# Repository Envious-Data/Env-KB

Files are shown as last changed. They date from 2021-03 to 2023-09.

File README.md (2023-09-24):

# Env-KB
 A custom mechanical keyboard inspired by the CFTKB Mysterium.
 
- Project Name: EnvKB80
- Nickname: Delirium

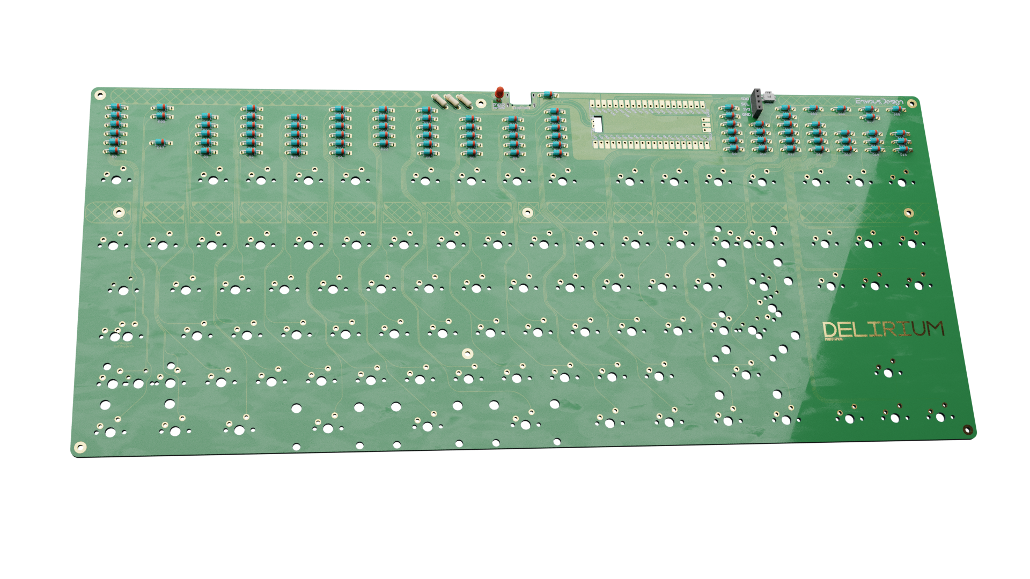
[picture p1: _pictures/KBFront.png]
Updated PCB


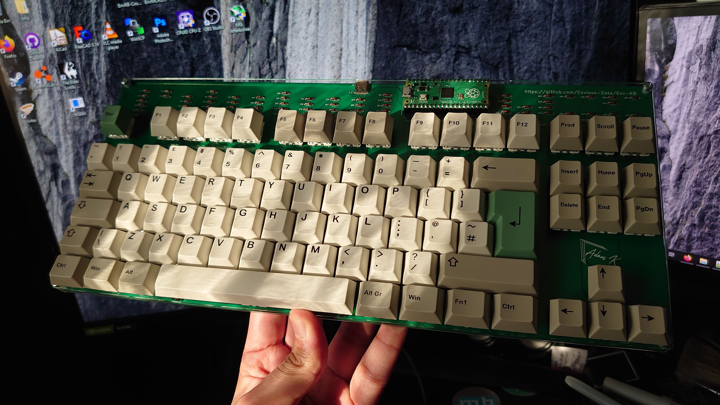
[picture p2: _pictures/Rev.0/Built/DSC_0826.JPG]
Rev0 Build


### About:
This is a raspberry pi pico powered keyboard I designed as I wanted something similar to a CFTKB Mysterium but easier to solder and a bit more robustly designed.

### Firmware
Pre-compiled firmwares can be found [here](https://github.com/Envious-Data/EnvKB-QMK/tree/main/_PREBUILTFIRMWARES)
- to flash a raspberry pi pico or any RP2040 board you need to hold the bootsel button while plugging in the USB, it'll show up as a USB drive called RP2-boot, you can then drag and drop a UF2 firmware file onto the pico, it will reboot its self.

### Parts
- 1x Type-C-31-M-14
- 90x 1n4148 DO-35
- 90x MX keyboard switches (5 pin advised if without switch plate)
- 3x 5.1K 1/4W resistors
- 1x 3mm LED
- 1x 1x04 2.54mm pin socket (optional oled)
- 1x Panasonic EVQPU SMD switch (optional reset)
- raspberry pi pico

- 10x m2 female standoffs 10mm 
- 20x m2 screws <5mm

(this list may not be totally accurate since I often forget what has changed inbetween when the readme is updated.

### Building
Most part orientations should be marked on the PCB however it is important to note that you NEED to connect the pads under the MCU to the respective pads on the board for USB to work, you also need 5.1K resistors to work with USB PD compatible ports.

the type-c port may be difficult for some to solder so use loads of flux and minimal amounts of solder, its best to solder the large 4 outer pins of the shell first.

### Why a RPI Pico?
uh well why not, I think it would be a nice example for people to use as a example.
When I came up with the idea of this keyboard there was 1 other raspberry pi pico keyboard so I decided it would be cool to make a keyboard.

### PCBWAY

PCBWAY (http://pcbway.com)

[PCBWAY](http://pcbway.com) Kindly sponsored a batch of PCBs of which you can see [pictures](_pictures/Hotswap/) of inside the pictures folder.

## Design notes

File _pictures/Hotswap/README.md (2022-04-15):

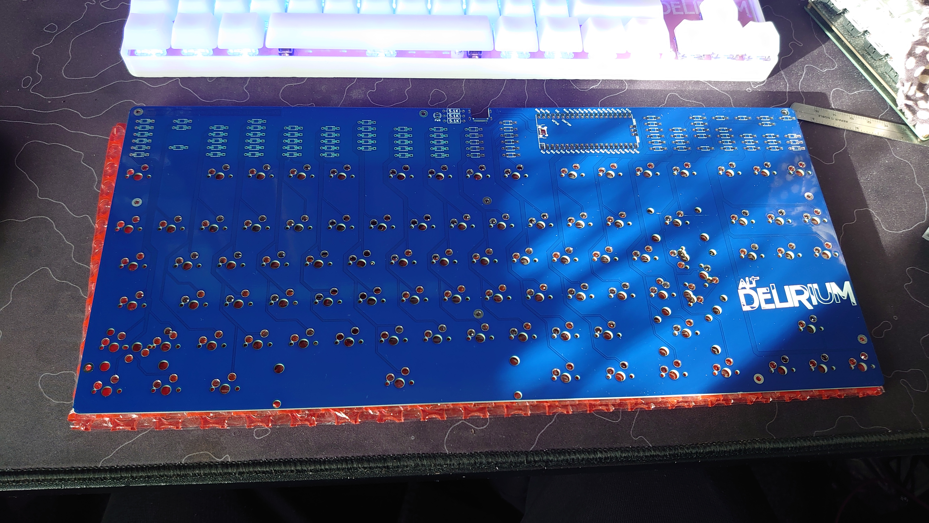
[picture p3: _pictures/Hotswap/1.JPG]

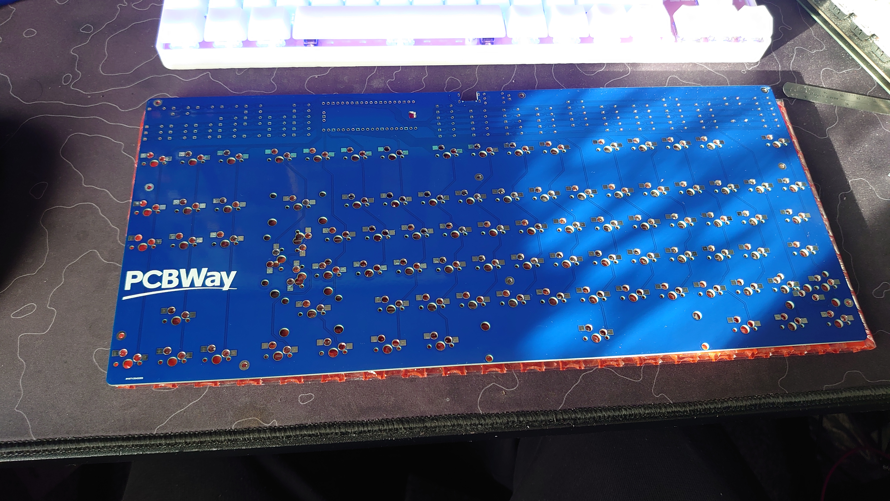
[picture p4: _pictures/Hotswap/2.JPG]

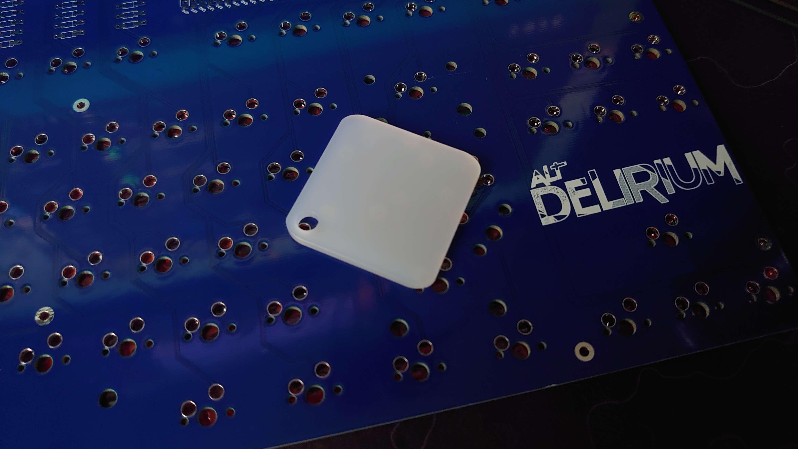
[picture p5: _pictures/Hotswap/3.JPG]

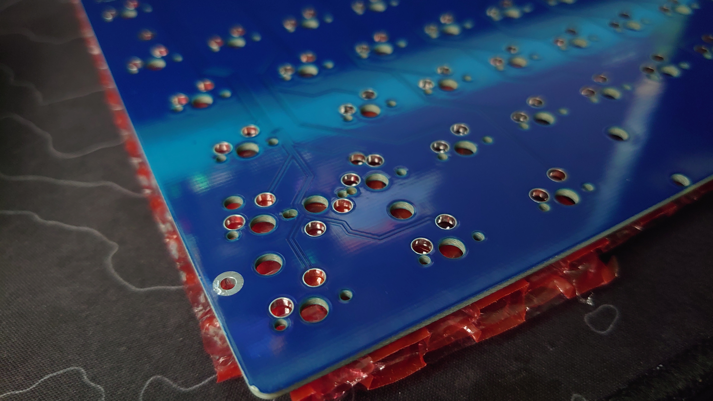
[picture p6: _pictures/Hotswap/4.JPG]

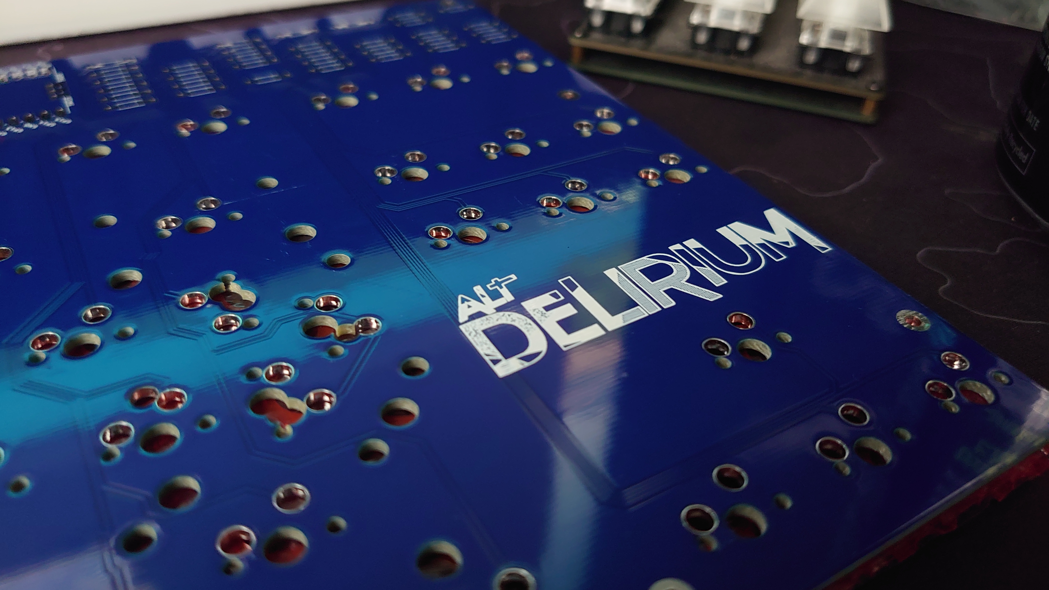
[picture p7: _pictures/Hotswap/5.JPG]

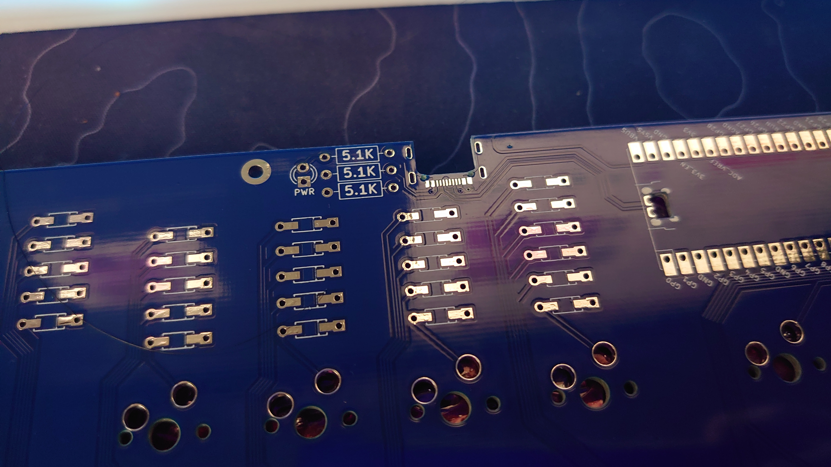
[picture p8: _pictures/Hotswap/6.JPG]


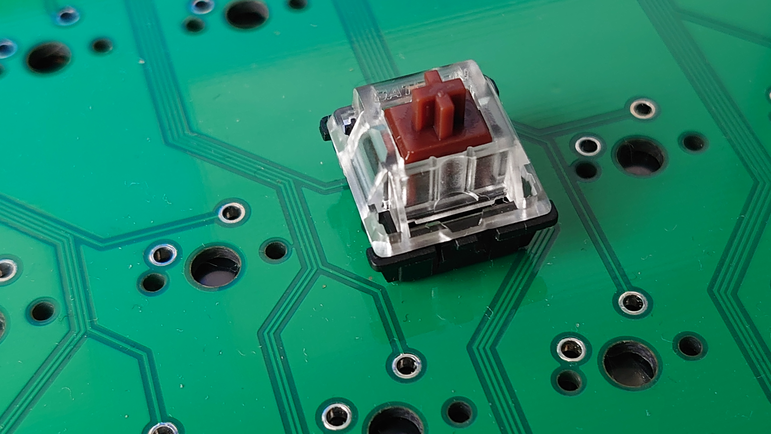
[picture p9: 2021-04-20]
_pictures/Rev.0/PCB10.JPG

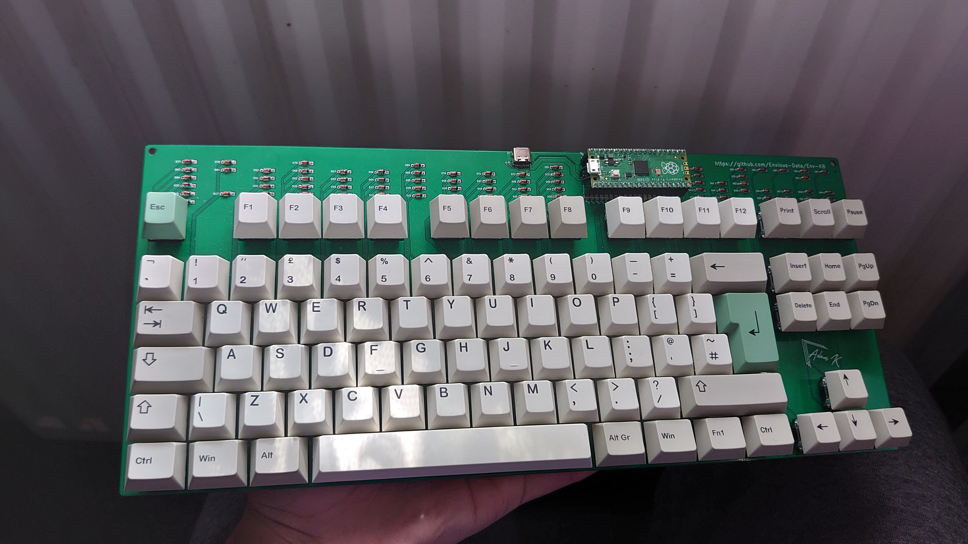
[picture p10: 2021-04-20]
_pictures/Rev.0/PCB3.JPG

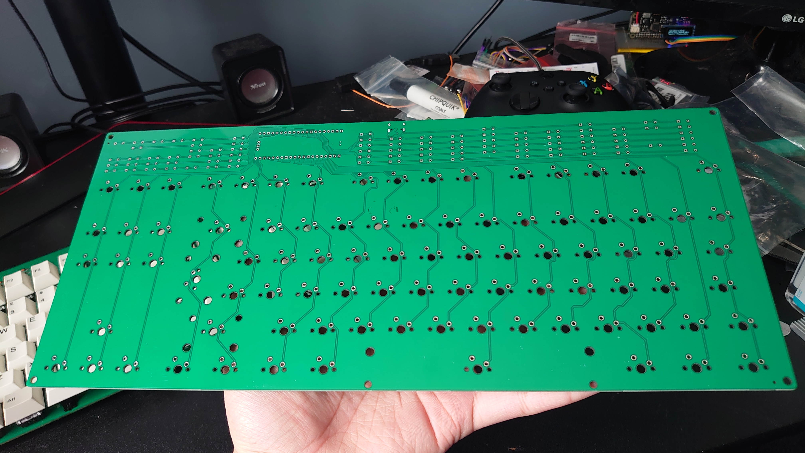
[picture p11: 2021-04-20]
_pictures/Rev.0/PCB8.JPG

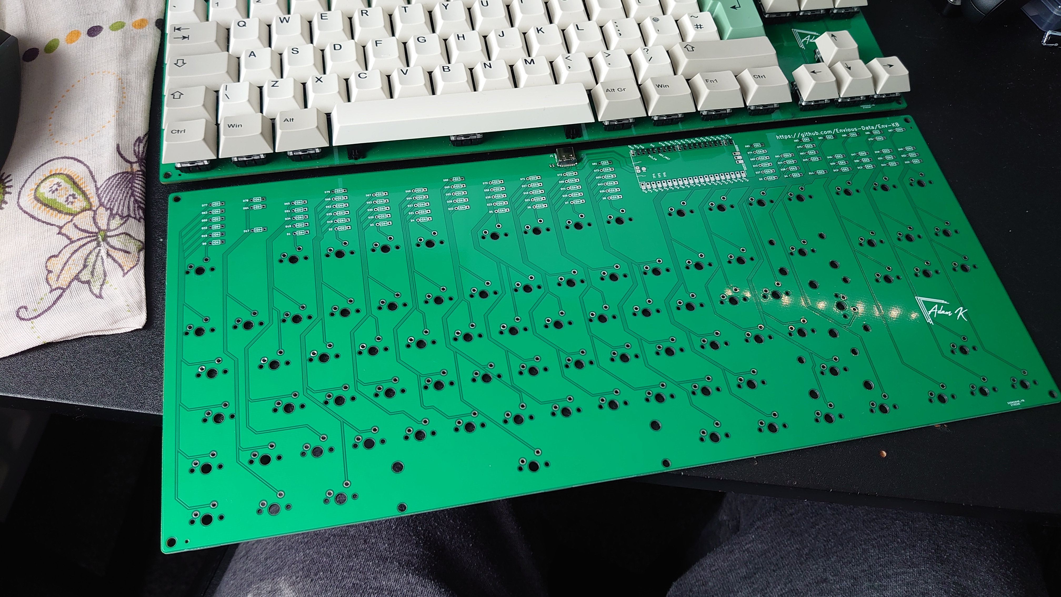
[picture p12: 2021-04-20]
_pictures/Rev.0/PCB6.JPG

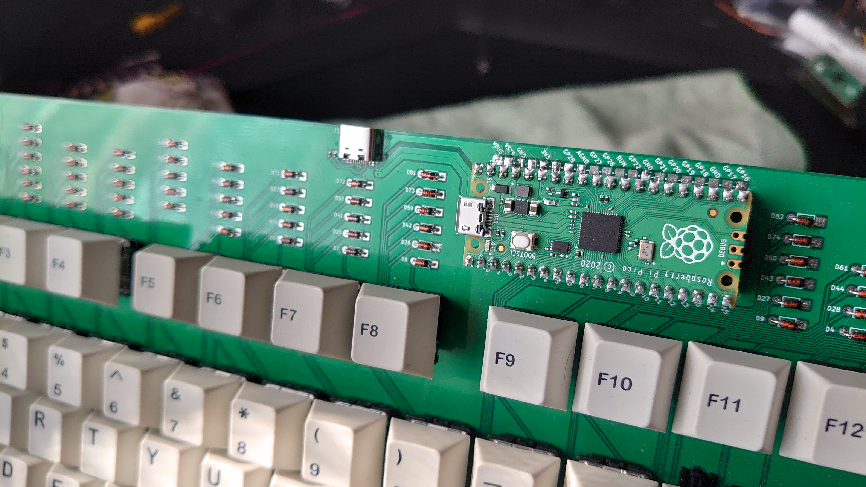
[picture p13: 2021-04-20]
_pictures/Rev.0/PCB5.JPG

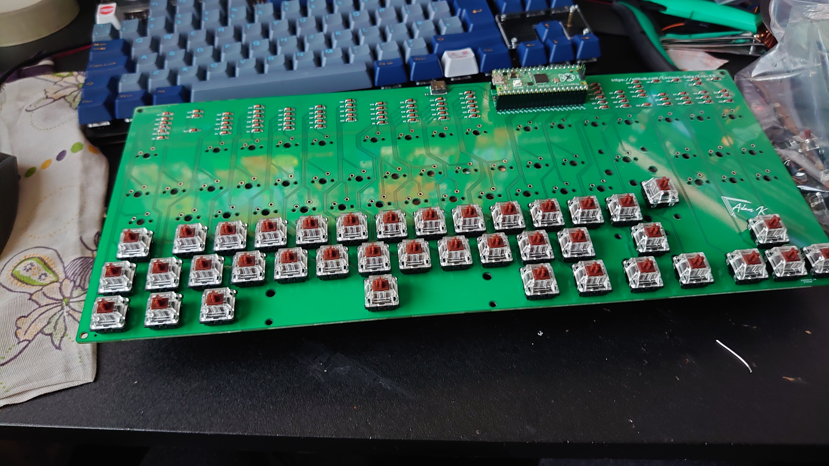
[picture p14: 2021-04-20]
_pictures/Rev.0/PCB1.JPG

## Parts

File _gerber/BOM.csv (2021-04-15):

Comment | Designator | Footprint | LCSC
D | D0,D1,D2,D3,D4,D5,D6,D7,D8,D9,D10,D11,D12,D13,D14,D15,D16,D17,D18,D19,D20,D21,D22,D23,D24,D25,D26,D27,D28,D29,D30,D31,D32,D33,D34,D35,D36,D37,D38,D39,D40,D41,D42,D43,D44,D45,D46,D47,D48,D49,D50,D51,D52,D53,D54,D55,D56,D57,D58,D59,D60,D61,D62,D63,D64,D65,D66,D67,D68,D69,D70,D71,D72,D73,D74,D75,D76,D77,D78,D79,D80,D81,D82,D83,D84,D85,D86,D87,D88 | CFTKB Bits:D_DO-35_SOD27_P5.08mm_Horizontal
MountingHole | H0,H1,H2,H3,H4,H5,H6,H7,H8,H9,H10 | MountingHole:MountingHole_2.2mm_M2
Conn_01x04 | I2CHeader0 | Connector_PinSocket_2.54mm:PinSocket_1x04_P2.54mm_Vertical
TYPE-C-31-M-12 | J0 | EM_Extras:USB_C_Receptacle_HRO_TYPE-C-31-M-12
KEYSW | K_0,K_1,K_2,K_3,K_4,K_5,K_6,K_7,K_8,K_9,K_10,K_11,K_12,K_13,K_14,K_15,K_16,K_17,K_18,K_19,K_20,K_21,K_22,K_23,K_24,K_25,K_26,K_27,K_28,K_30,K_31,K_32,K_34,K_35,K_36,K_37,K_38,K_39,K_40,K_41,K_42,K_43,K_44,K_45,K_47,K_48,K_49,K_51,K_52,K_53,K_54,K_55,K_56,K_57,K_58,K_59,K_60,K_61,K_62,K_65,K_66,K_67,K_68,K_69,K_70,K_71,K_72,K_73,K_74,K_75,K_77,K_86,K_87,K_88 | MX_only:MXOnly-1U-NoLED
KEYSW | K_29 | MX_only:MXOnly-2U-NoLED
KEYSW | K_33,K_46 | MX_only:MXOnly-1.5U-NoLED
KEYSW | K_50 | MX_only:MXOnly-1.75U-NoLED
MX-NoLED | K_63 | MX_only:MXOnly-ISO-ROTATED-ReversedStabilizers-NoLED
MX-NoLED | K_63B1 | MX_only:MXOnly-2.25U-NoLED
KEYSW | K_64,K_78,K_79,K_80,K_82,K_83,K_84,K_85 | MX_only:MXOnly-1.25U-NoLED
KEYSW | K_64B1 | MX_only:MXOnly-2.25U-NoLED
KEYSW | K_76 | MX_only:MXOnly-2.75U-NoLED
KEYSW | K_81 | MX_only:MXOnly-6.25U-ReversedStabilizers-NoLED
Green Power Led | PowerLED0 | LED_SMD:LED_0805_2012Metric_Castellated
1K Resistor | PowerLedResistor0 | Resistor_SMD:R_0805_2012Metric
5.1kohm | RESISTOR0,RESISTOR1 | Resistor_SMD:R_0402_1005Metric
Pico | RPI0 | EM_Extras:RPi_Pico_SMD_TH
B3F-1000 | SW-RST0 | EM_Extras:SW_B3F-1000

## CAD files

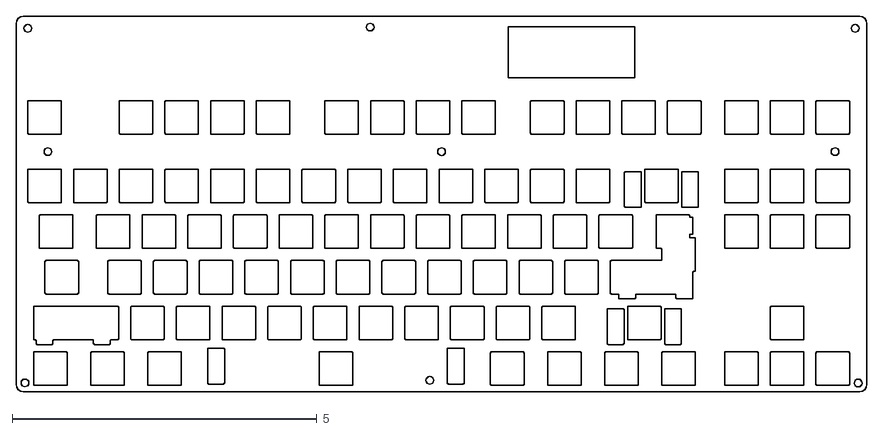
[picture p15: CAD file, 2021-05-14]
_gerber/EnvKB-R1-Front.dxf
14.0 x 6.16

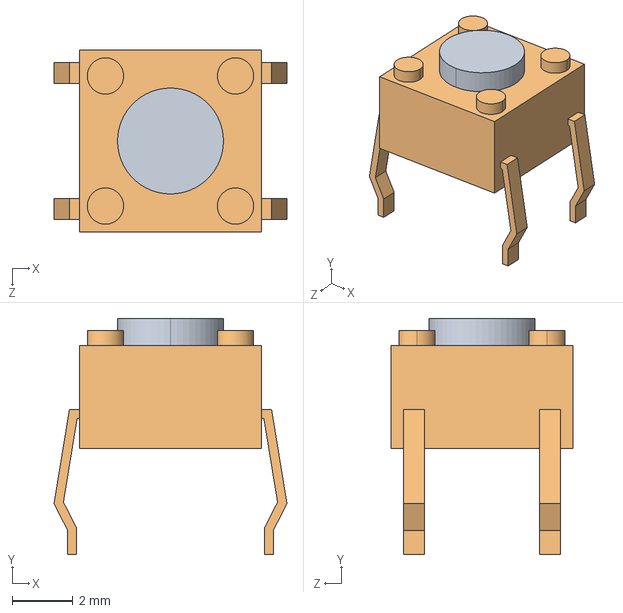
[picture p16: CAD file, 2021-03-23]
_KiCadLibs/Schematic_Library/B3F-1000.step
7.70 x 7.80 x 6.00 mm
B3F_1000_BUTTON
B3F_1000_BASE

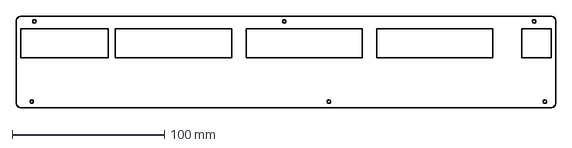
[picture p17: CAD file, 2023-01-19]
Production Files/Laser Cut files/TopCover.dxf
353.7 x 59.7 mm

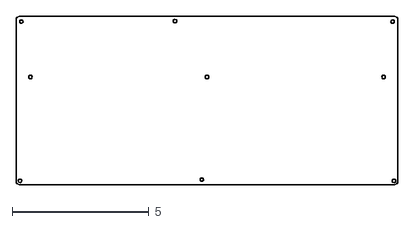
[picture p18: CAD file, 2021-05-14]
_gerber/EnvKB-R1-Back.dxf
14.0 x 6.16

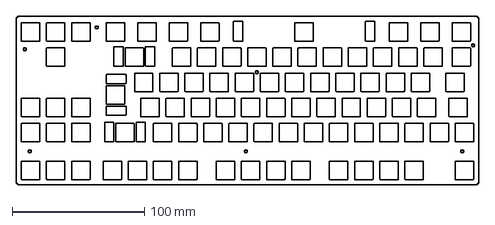
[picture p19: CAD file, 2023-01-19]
Production Files/Laser Cut files/SwitchPlate.dxf
350.6 x 127.8 mm

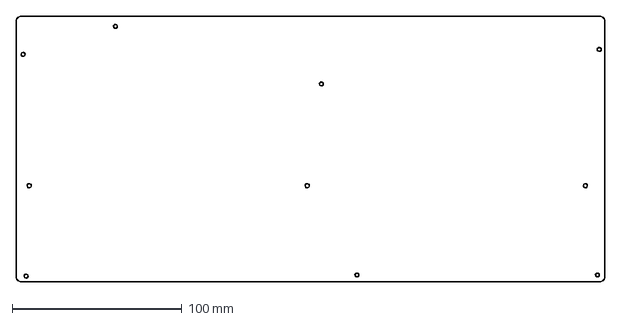
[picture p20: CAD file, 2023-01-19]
Production Files/Laser Cut files/BackPlate.dxf
347.0 x 156.3 mm

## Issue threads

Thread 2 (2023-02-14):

Help with HS + RGB version

racsor17, 2023-02-14:
Hi, this is my first time building my own keyboard. Do I need to get and solder different materials that aren't in the list? Like RGB LEDs or anything to do the "hot-swap thing"? There is any building guide? To order the PCB in PCBWAY, I just have to drag the files and buy it?
I just love this keyboard, you've done such a great job!

racsor17, 2023-02-14:
LED's needsSMT solder??

Envious-Data, 2023-02-14:
You'll have to download KiCad and generate gerbers, CPL and BOM for PCB way since what you might find in the gerber folder is for JLCPCB.

the LEDs can be hand soldered but they can be difficult if you get them from aliexpress, you are looking for SK6812 mini-e.

the hotswap sockets are typical kailh ones you can buy those from a number of stores.

diodes are 1n4148 Do-35s

racsor17, 2023-02-16:
Thank you!

Closed 2023-02-16.

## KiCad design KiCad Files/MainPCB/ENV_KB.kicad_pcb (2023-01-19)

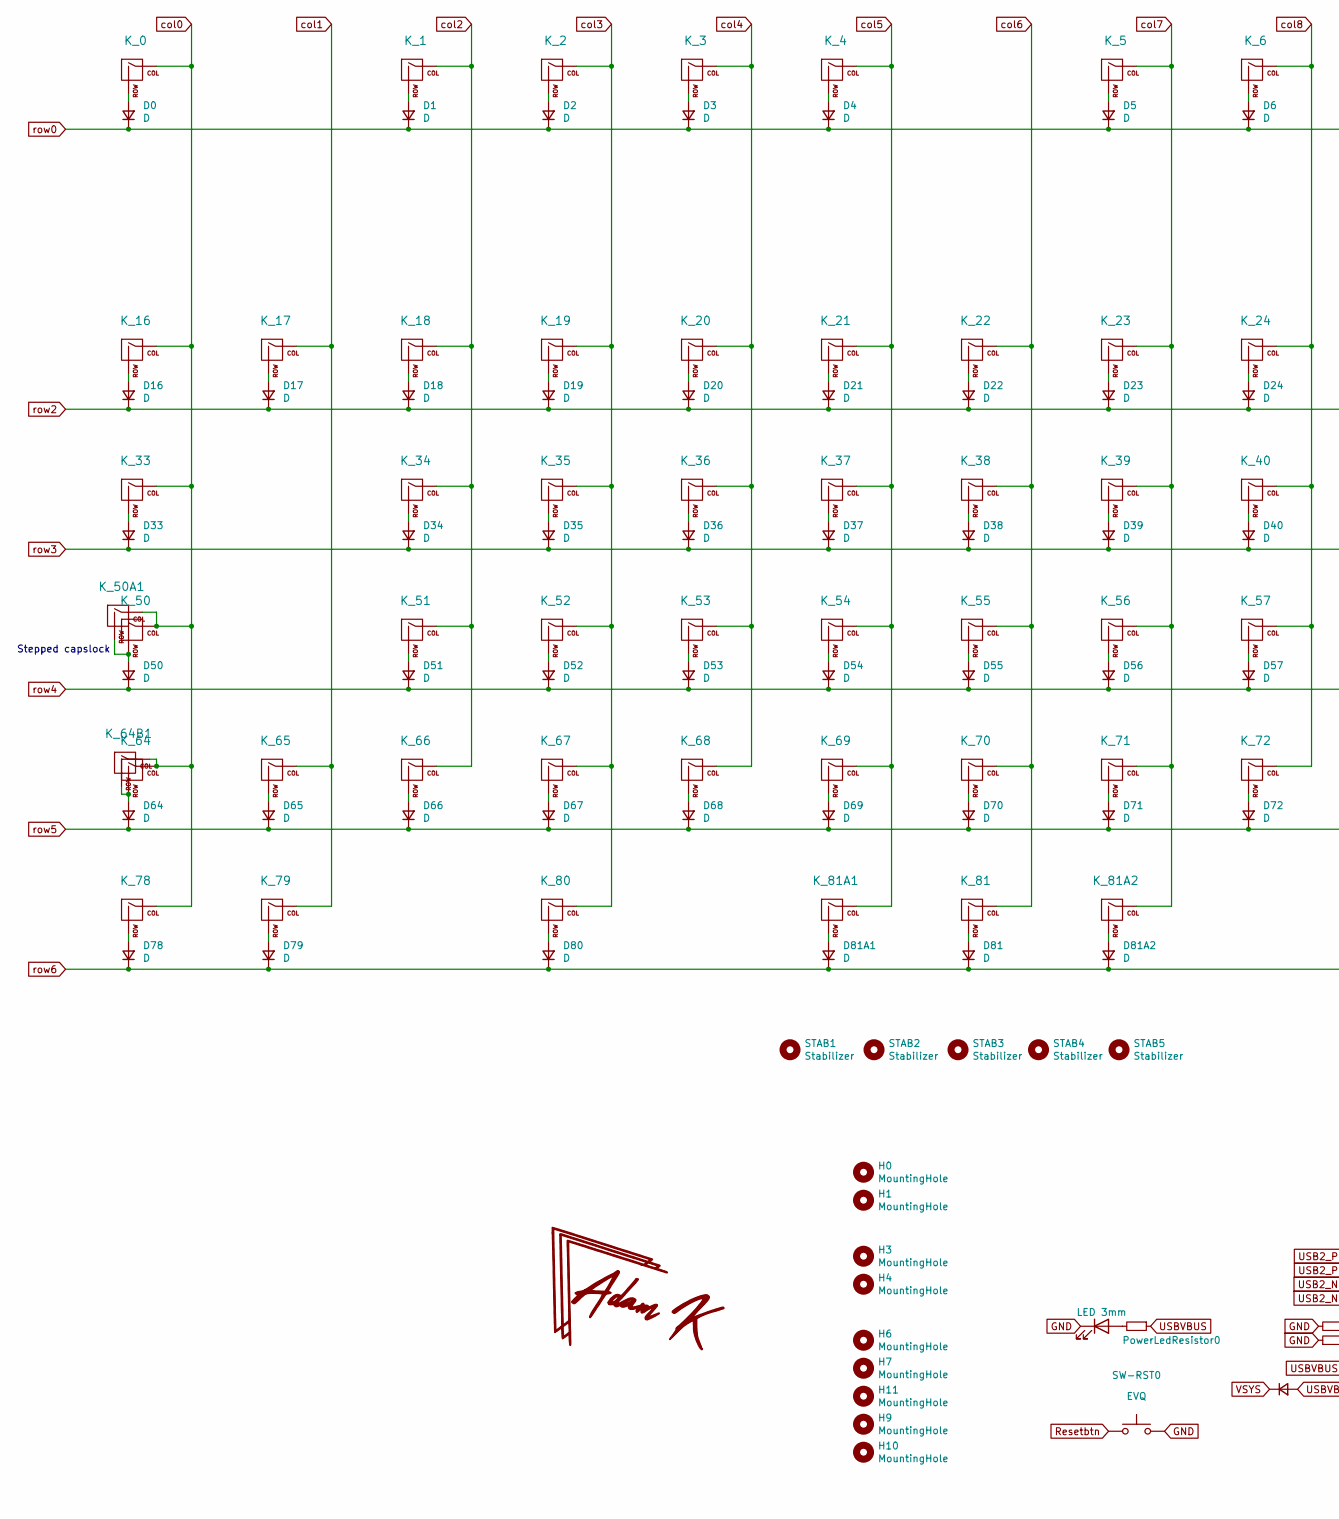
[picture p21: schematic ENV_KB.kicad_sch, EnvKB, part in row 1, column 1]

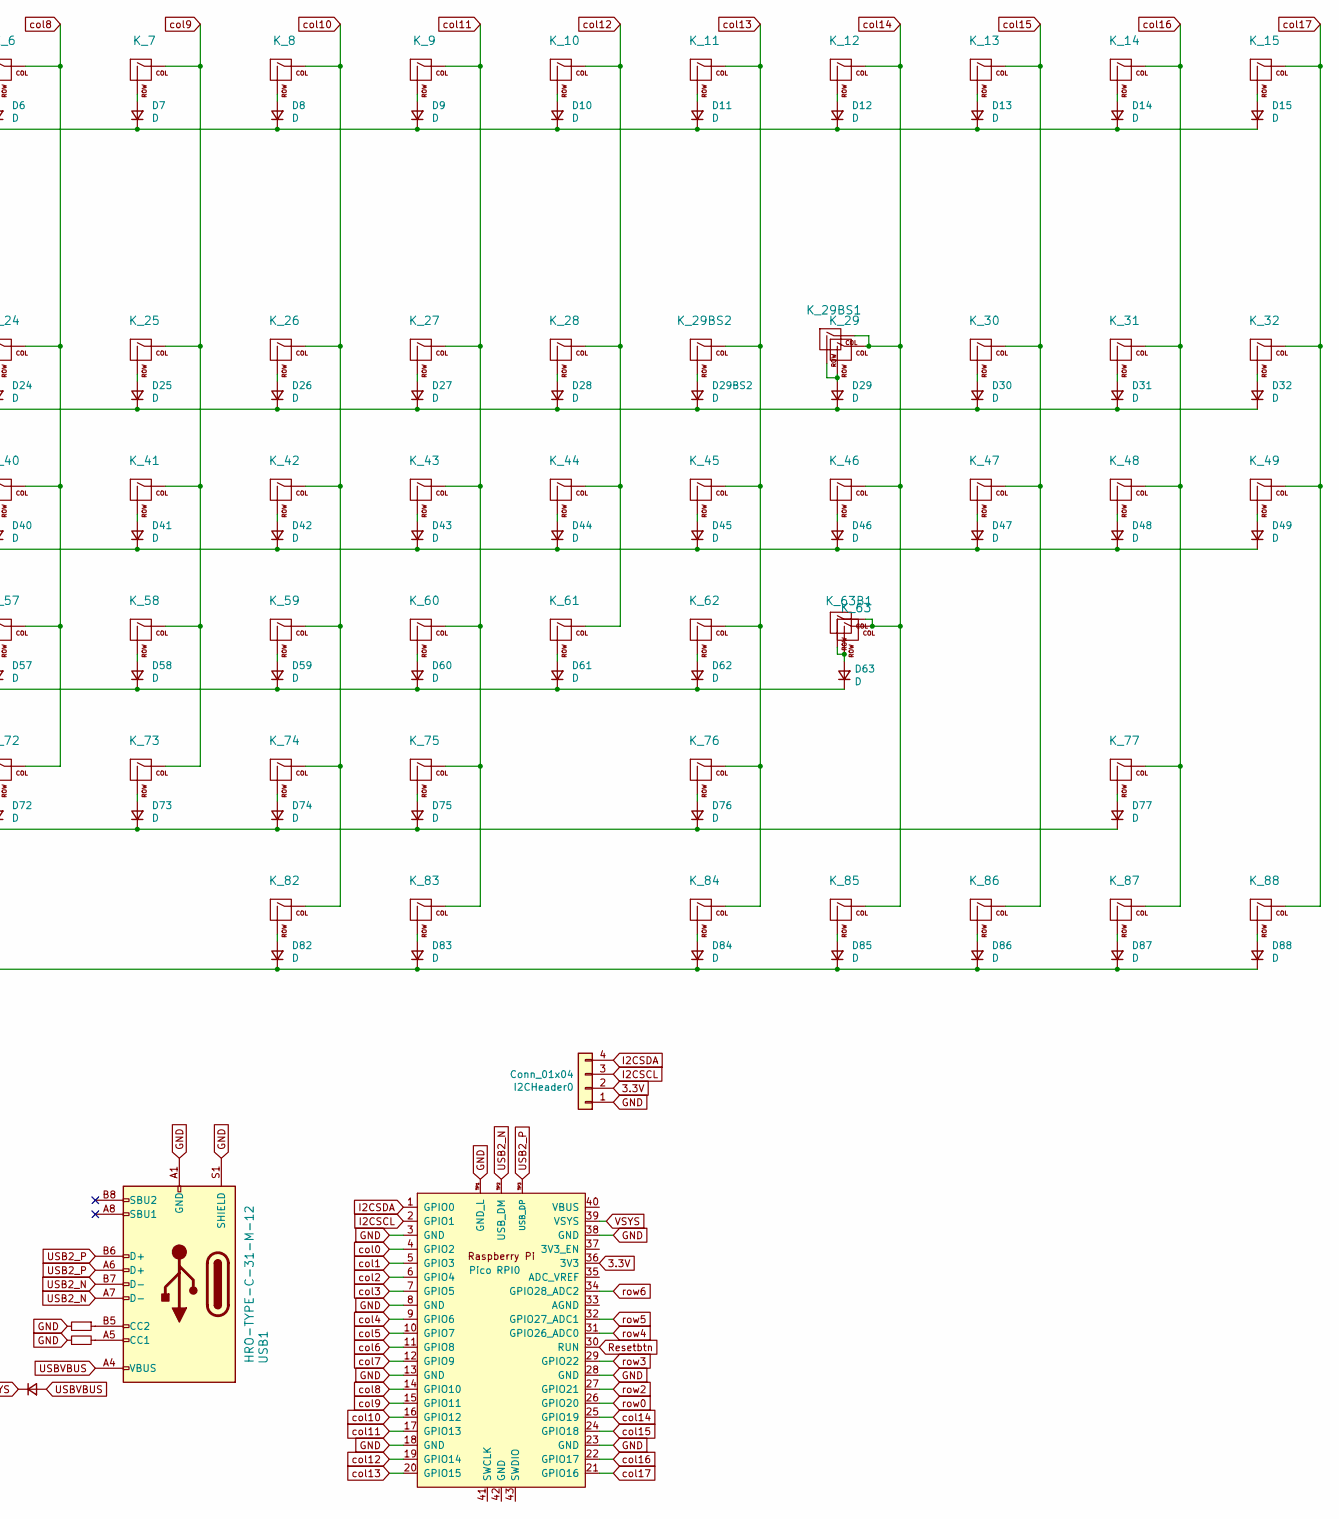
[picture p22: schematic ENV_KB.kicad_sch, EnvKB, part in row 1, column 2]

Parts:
D0, D1, D2, D3, D4, D5, D6, D7, D8, D9, D10, D11, D12, D13, D14, D15, D16, D17, D18, D19, D20, D21, D22, D23, D24, D25, D26, D27, D28, D29, D29BS2, D30, D31, D32, D33, D34, D35, D36, D37, D38, D39, D40, D41, D42, D43, D44, D45, D46, D47, D48, D49, D50, D51, D52, D53, D54, D55, D56, D57, D58, D59, D60, D61, D62, D63, D64, D65, D66, D67, D68, D69, D70, D71, D72, D73, D74, D75, D76, D77, D78, D79, D80, D81, D81A1, D81A2, D82, D83, D84, D85, D86, D87, D88: D; D_DO-35_SOD27_P7.62mm_Horizontal
D89: 1n4002; D_DO-35_SOD27_P7.62mm_Horizontal
H0, H1, H3, H4, H6, H7, H9, H10, H11: MountingHole; MountingHole_2.2mm_M2_Pad
I2CHeader0: Conn_01x04; PinSocket_1x04_P2.54mm_Vertical
K_0, K_1, K_2, K_3, K_4, K_5, K_6, K_7, K_8, K_9, K_10, K_11, K_12, K_13, K_14, K_15, K_16, K_17, K_18, K_19, K_20, K_21, K_22, K_23, K_24, K_25, K_26, K_27, K_28, K_29, K_29BS1, K_29BS2, K_30, K_31, K_32, K_34, K_35, K_36, K_37, K_38, K_39, K_40, K_41, K_42, K_43, K_44, K_45, K_47, K_48, K_49, K_51, K_52, K_53, K_54, K_55, K_56, K_57, K_58, K_59, K_60, K_61, K_62, K_65, K_66, K_67, K_68, K_69, K_70, K_71, K_72, K_73, K_74, K_75, K_77, K_81, K_81A1, K_81A2, K_86, K_87, K_88: KEYSW; MXOnly-1U-NoLED
K_33, K_46: KEYSW; MXOnly-1.5U-NoLED
K_50: KEYSW; MXOnly-1.75U-NoLED
K_50A1, K_64, K_78, K_79, K_80, K_82, K_83, K_84, K_85: KEYSW; MXOnly-1.25U-NoLED
K_63: MX-NoLED; MXOnly-ISO-ROTATED-ReversedStabilizers-NoLED
K_63B1: MX-NoLED; MXOnly-2.25U-NoLED
K_64B1: KEYSW; MXOnly-2.25U-NoLED
K_76: KEYSW; MXOnly-2.75U-NoLED
PowerLED0: LED 3mm; LED_D3.0mm
PowerLedResistor0: 47K Resistor; R_Axial_DIN0207_L6.3mm_D2.5mm_P7.62mm_Horizontal; LCSC C17513
RESISTOR0, RESISTOR1: 5.1k; R_Axial_DIN0207_L6.3mm_D2.5mm_P7.62mm_Horizontal; LCSC C25905
RPI0: Pico; RPi_Pico_SMD_TH
STAB1, STAB2, STAB3, STAB4, STAB5: Stabilizer; Stabilizer_Cherry_MX_2u
SW-RST0: EVQ; Panasonic_EVQPUL_EVQPUC
USB1: HRO-TYPE-C-31-M-12; USB_C_TYPE-C-31-M-14; LCSC C165948

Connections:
3.3V: I2CHeader0.2, RPI0.36 (3V3)
GND: I2CHeader0.1, PowerLED0.1 (K), RESISTOR0.2, RESISTOR1.1, RPI0.3 (GND), RPI0.8 (GND), RPI0.13 (GND), RPI0.18 (GND), RPI0.23 (GND), RPI0.28 (GND), RPI0.38 (GND), RPI0.TP1 (GND_L), SW-RST0.2, USB1.A1 (GND), USB1.A12 (GND), USB1.B1 (GND), USB1.B12 (GND), USB1.S1 (SHIELD)
I2CSCL: I2CHeader0.3, RPI0.2 (GPIO1)
I2CSDA: I2CHeader0.4, RPI0.1 (GPIO0)
unnamed 4: D0.2 (A), K_0.2 (ROW); also elsewhere on the board
unnamed: D1.2 (A), K_1.2 (ROW)
unnamed: D2.2 (A), K_2.2 (ROW)
unnamed: D3.2 (A), K_3.2 (ROW)
unnamed: D4.2 (A), K_4.2 (ROW)
unnamed: D5.2 (A), K_5.2 (ROW)
unnamed: D6.2 (A), K_6.2 (ROW)
unnamed: D7.2 (A), K_7.2 (ROW)
unnamed: D8.2 (A), K_8.2 (ROW)
unnamed: D9.2 (A), K_9.2 (ROW)
unnamed: D10.2 (A), K_10.2 (ROW)
unnamed: D11.2 (A), K_11.2 (ROW)
unnamed: D12.2 (A), K_12.2 (ROW)
unnamed: D13.2 (A), K_13.2 (ROW)
unnamed: D14.2 (A), K_14.2 (ROW)
unnamed: D15.2 (A), K_15.2 (ROW)
unnamed: D16.2 (A), K_16.2 (ROW)
unnamed: D17.2 (A), K_17.2 (ROW)
unnamed: D18.2 (A), K_18.2 (ROW)
unnamed: D19.2 (A), K_19.2 (ROW)
unnamed: D20.2 (A), K_20.2 (ROW)
unnamed: D21.2 (A), K_21.2 (ROW)
unnamed: D22.2 (A), K_22.2 (ROW)
unnamed: D23.2 (A), K_23.2 (ROW)
unnamed: D24.2 (A), K_24.2 (ROW)
unnamed: D25.2 (A), K_25.2 (ROW)
unnamed: D26.2 (A), K_26.2 (ROW)
unnamed: D27.2 (A), K_27.2 (ROW)
unnamed: D28.2 (A), K_28.2 (ROW)
unnamed: D29.2 (A), K_29.2 (ROW), K_29BS1.2 (ROW)
unnamed: D29BS2.2 (A), K_29BS2.2 (ROW)
unnamed: D30.2 (A), K_30.2 (ROW)
unnamed: D31.2 (A), K_31.2 (ROW)
unnamed: D32.2 (A), K_32.2 (ROW)
unnamed: D33.2 (A), K_33.2 (ROW)
unnamed: D34.2 (A), K_34.2 (ROW)
unnamed: D35.2 (A), K_35.2 (ROW)
unnamed: D36.2 (A), K_36.2 (ROW)
unnamed: D37.2 (A), K_37.2 (ROW)
unnamed: D38.2 (A), K_38.2 (ROW)
unnamed: D39.2 (A), K_39.2 (ROW)
unnamed: D40.2 (A), K_40.2 (ROW)
unnamed: D41.2 (A), K_41.2 (ROW)
unnamed: D42.2 (A), K_42.2 (ROW)
unnamed: D43.2 (A), K_43.2 (ROW)
unnamed: D44.2 (A), K_44.2 (ROW)
unnamed: D45.2 (A), K_45.2 (ROW)
unnamed: D46.2 (A), K_46.2 (ROW)
unnamed: D47.2 (A), K_47.2 (ROW)
unnamed: D48.2 (A), K_48.2 (ROW)
unnamed: D49.2 (A), K_49.2 (ROW)
unnamed: D50.2 (A), K_50.2 (ROW), K_50A1.2 (ROW)
unnamed: D51.2 (A), K_51.2 (ROW)
unnamed: D52.2 (A), K_52.2 (ROW)
unnamed: D53.2 (A), K_53.2 (ROW)
unnamed: D54.2 (A), K_54.2 (ROW)
unnamed: D55.2 (A), K_55.2 (ROW)
unnamed: D56.2 (A), K_56.2 (ROW)
unnamed: D57.2 (A), K_57.2 (ROW)
unnamed: D58.2 (A), K_58.2 (ROW)
unnamed: D59.2 (A), K_59.2 (ROW)
unnamed: D60.2 (A), K_60.2 (ROW)
unnamed: D61.2 (A), K_61.2 (ROW)
unnamed: D62.2 (A), K_62.2 (ROW)
unnamed: D63.2 (A), K_63.2 (ROW), K_63B1.2 (ROW)
unnamed: D64.2 (A), K_64.2 (ROW), K_64B1.2 (ROW)
unnamed: D65.2 (A), K_65.2 (ROW)
unnamed: D66.2 (A), K_66.2 (ROW)
unnamed: D67.2 (A), K_67.2 (ROW)
unnamed: D68.2 (A), K_68.2 (ROW)
unnamed: D69.2 (A), K_69.2 (ROW)
unnamed: D70.2 (A), K_70.2 (ROW)
unnamed: D71.2 (A), K_71.2 (ROW)
unnamed: D72.2 (A), K_72.2 (ROW)
unnamed: D73.2 (A), K_73.2 (ROW)
unnamed: D74.2 (A), K_74.2 (ROW)
unnamed: D75.2 (A), K_75.2 (ROW)
unnamed: D76.2 (A), K_76.2 (ROW)
unnamed: D77.2 (A), K_77.2 (ROW)
unnamed: D78.2 (A), K_78.2 (ROW)
unnamed: D79.2 (A), K_79.2 (ROW)
unnamed: D80.2 (A), K_80.2 (ROW)
unnamed: D81.2 (A), K_81.2 (ROW)
unnamed: D81A1.2 (A), K_81A1.2 (ROW)
unnamed: D81A2.2 (A), K_81A2.2 (ROW)
unnamed: D82.2 (A), K_82.2 (ROW)
unnamed: D83.2 (A), K_83.2 (ROW)
unnamed: D84.2 (A), K_84.2 (ROW)
unnamed: D85.2 (A), K_85.2 (ROW)
unnamed: D86.2 (A), K_86.2 (ROW)
unnamed: D87.2 (A), K_87.2 (ROW)
unnamed: D88.2 (A), K_88.2 (ROW)
unnamed: PowerLED0.2 (A), PowerLedResistor0.2
unnamed: RESISTOR0.1, USB1.B5 (CC2)
unnamed: RESISTOR1.2, USB1.A5 (CC1)
Resetbtn: RPI0.30 (RUN), SW-RST0.1
USB2_N: RPI0.TP2 (USB_DM), USB1.A7 (D-), USB1.B7 (D-)
USB2_P: RPI0.TP3 (USB_DP), USB1.A6 (D+), USB1.B6 (D+)
USBVBUS: D89.2 (A), PowerLedResistor0.1, USB1.A4 (VBUS), USB1.A9 (VBUS), USB1.B4 (VBUS), USB1.B9 (VBUS)
VSYS: D89.1 (K), RPI0.39 (VSYS)
col0: K_0.1 (COL), K_16.1 (COL), K_33.1 (COL), K_50.1 (COL), K_50A1.1 (COL), K_64.1 (COL), K_64B1.1 (COL), K_78.1 (COL), RPI0.4 (GPIO2); also elsewhere on the board
col1: K_17.1 (COL), K_65.1 (COL), K_79.1 (COL), RPI0.5 (GPIO3)
col2: K_1.1 (COL), K_18.1 (COL), K_34.1 (COL), K_51.1 (COL), K_66.1 (COL), RPI0.6 (GPIO4)
col3: K_2.1 (COL), K_19.1 (COL), K_35.1 (COL), K_52.1 (COL), K_67.1 (COL), K_80.1 (COL), RPI0.7 (GPIO5)
col4: K_3.1 (COL), K_20.1 (COL), K_36.1 (COL), K_53.1 (COL), K_68.1 (COL), RPI0.9 (GPIO6)
col5: K_4.1 (COL), K_21.1 (COL), K_37.1 (COL), K_54.1 (COL), K_69.1 (COL), K_81A1.1 (COL), RPI0.10 (GPIO7)
col6: K_22.1 (COL), K_38.1 (COL), K_55.1 (COL), K_70.1 (COL), K_81.1 (COL), RPI0.11 (GPIO8)
col7: K_5.1 (COL), K_23.1 (COL), K_39.1 (COL), K_56.1 (COL), K_71.1 (COL), K_81A2.1 (COL), RPI0.12 (GPIO9)
col8: K_6.1 (COL), K_24.1 (COL), K_40.1 (COL), K_57.1 (COL), K_72.1 (COL), RPI0.14 (GPIO10)
col9: K_7.1 (COL), K_25.1 (COL), K_41.1 (COL), K_58.1 (COL), K_73.1 (COL), RPI0.15 (GPIO11)
col10: K_8.1 (COL), K_26.1 (COL), K_42.1 (COL), K_59.1 (COL), K_74.1 (COL), K_82.1 (COL), RPI0.16 (GPIO12)
col11: K_9.1 (COL), K_27.1 (COL), K_43.1 (COL), K_60.1 (COL), K_75.1 (COL), K_83.1 (COL), RPI0.17 (GPIO13)
col12: K_10.1 (COL), K_28.1 (COL), K_44.1 (COL), K_61.1 (COL), RPI0.19 (GPIO14)
col13: K_11.1 (COL), K_29BS2.1 (COL), K_45.1 (COL), K_62.1 (COL), K_76.1 (COL), K_84.1 (COL), RPI0.20 (GPIO15)
col14: K_12.1 (COL), K_29.1 (COL), K_29BS1.1 (COL), K_46.1 (COL), K_63.1 (COL), K_63B1.1 (COL), K_85.1 (COL), RPI0.25 (GPIO19)
col15: K_13.1 (COL), K_30.1 (COL), K_47.1 (COL), K_86.1 (COL), RPI0.24 (GPIO18)
col16: K_14.1 (COL), K_31.1 (COL), K_48.1 (COL), K_77.1 (COL), K_87.1 (COL), RPI0.22 (GPIO17)
col17: K_15.1 (COL), K_32.1 (COL), K_49.1 (COL), K_88.1 (COL), RPI0.21 (GPIO16)
row0: D0.1 (K), D1.1 (K), D2.1 (K), D3.1 (K), D4.1 (K), D5.1 (K), D6.1 (K), D7.1 (K), D8.1 (K), D9.1 (K), D10.1 (K), D11.1 (K), D12.1 (K), D13.1 (K), D14.1 (K), D15.1 (K), RPI0.26 (GPIO20)
row2: D16.1 (K), D17.1 (K), D18.1 (K), D19.1 (K), D20.1 (K), D21.1 (K), D22.1 (K), D23.1 (K), D24.1 (K), D25.1 (K), D26.1 (K), D27.1 (K), D28.1 (K), D29.1 (K), D29BS2.1 (K), D30.1 (K), D31.1 (K), D32.1 (K), RPI0.27 (GPIO21)
row3: D33.1 (K), D34.1 (K), D35.1 (K), D36.1 (K), D37.1 (K), D38.1 (K), D39.1 (K), D40.1 (K), D41.1 (K), D42.1 (K), D43.1 (K), D44.1 (K), D45.1 (K), D46.1 (K), D47.1 (K), D48.1 (K), D49.1 (K), RPI0.29 (GPIO22)
row4: D50.1 (K), D51.1 (K), D52.1 (K), D53.1 (K), D54.1 (K), D55.1 (K), D56.1 (K), D57.1 (K), D58.1 (K), D59.1 (K), D60.1 (K), D61.1 (K), D62.1 (K), D63.1 (K), RPI0.31 (GPIO26_ADC0)
row5: D64.1 (K), D65.1 (K), D66.1 (K), D67.1 (K), D68.1 (K), D69.1 (K), D70.1 (K), D71.1 (K), D72.1 (K), D73.1 (K), D74.1 (K), D75.1 (K), D76.1 (K), D77.1 (K), RPI0.32 (GPIO27_ADC1)
row6: D78.1 (K), D79.1 (K), D80.1 (K), D81.1 (K), D81A1.1 (K), D81A2.1 (K), D82.1 (K), D83.1 (K), D84.1 (K), D85.1 (K), D86.1 (K), D87.1 (K), D88.1 (K), RPI0.34 (GPIO28_ADC2)

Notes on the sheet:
Stepped capslock

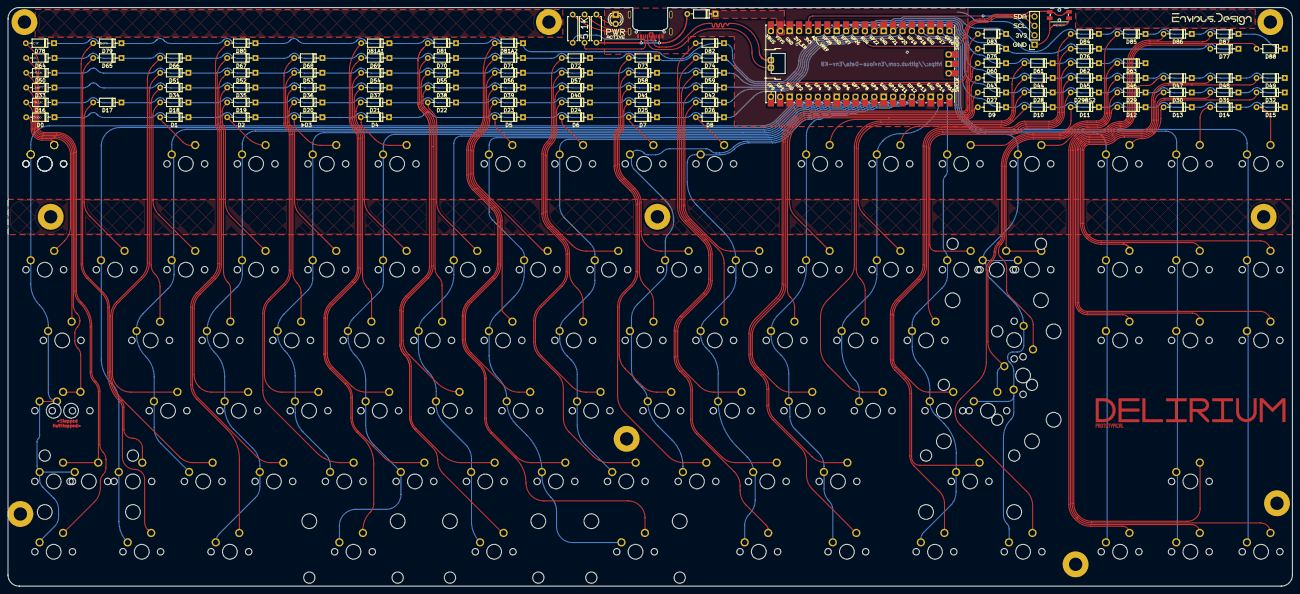
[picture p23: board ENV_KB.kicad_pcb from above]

Board: 2 copper layers, 347.0 x 156.3 mm, 232 parts (0 on the bottom side), 128 nets.

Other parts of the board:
H4#2: MountingHole; MountingHole_2.2mm_M2_Pad
K_0#2: KEYSW; MXOnly-1U-NoLED
kibuzzard-628ADF99, kibuzzard-628ADF99#2: G***; kibuzzard-628ADF99
kibuzzard-628AE7EF: G***; kibuzzard-628AE7EF
kibuzzard-628AE7FB: G***; kibuzzard-628AE7FB
kibuzzard-628AE8A6: G***; kibuzzard-628AE8A6
kibuzzard-628AE061, kibuzzard-628AE061#2: G***; kibuzzard-628AE061
kibuzzard-628AE80F: G***; kibuzzard-628AE80F
kibuzzard-628AE82F: G***; kibuzzard-628AE82F
kibuzzard-628AE768: G***; kibuzzard-628AE768
kibuzzard-628AE805: G***; kibuzzard-628AE805
kibuzzard-628AE860: G***; kibuzzard-628AE860
kibuzzard-628AE868: G***; kibuzzard-628AE868
kibuzzard-628AE874: G***; kibuzzard-628AE874
kibuzzard-628AE882: G***; kibuzzard-628AE882
kibuzzard-628AE933: G***; kibuzzard-628AE933
kibuzzard-628AE966: G***; kibuzzard-628AE966
kibuzzard-628AEA91: G***; kibuzzard-628AEA91
kibuzzard-6250C4E7: G***; kibuzzard-6250C4E7

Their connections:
unnamed 4: K_0#2.2 (ROW); also elsewhere on the board
col0: K_0#2.1 (COL); also elsewhere on the board

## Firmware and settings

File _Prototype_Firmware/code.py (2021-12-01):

#PiPi-GHERKIN - Raspberry Pi PICO
#Rpi pico keyboard keymap, I used the gherkin keymap as a example :)
print("Starting")

#run the led
import board
import pwmio
import time
import supervisor

led = pwmio.PWMOut(board.GP25, frequency=1, duty_cycle=1024, variable_frequency=True)

exec(open('oled.py').read())



import board
from kmk.kmk_keyboard import KMKKeyboard
from kmk.keys import KC
from kmk.matrix import DiodeOrientation
from kmk.modules.layers import Layers
from kmk.keys import KC, make_key
envkb = KMKKeyboard()

envkb.col_pins = (board.GP2, board.GP3, board.GP4, board.GP5, board.GP6, board.GP7, board.GP8, board.GP9, board.GP10, board.GP11, board.GP12, board.GP13, board.GP14, board.GP15, board.GP19, board.GP18, board.GP17, board.GP16)
envkb.row_pins = (board.GP20, board.GP21, board.GP22, board.GP26, board.GP27, board.GP28)
envkb.diode_orientation = DiodeOrientation.COLUMNS

rollover_cols_every_rows = 4
envkb.diode_orientation = DiodeOrientation.COLUMNS
envkb.debug_enabled = False

layers = Layers()
envkb.modules = [layers]

nokey = KC.NO
envkb.keymap = [
    [
    #Layer 0?
        KC.ESC, nokey, KC.F1, KC.F2, KC.F3, KC.F4, nokey, KC.F5, KC.F6, KC.F7, KC.F8, KC.F9, KC.F10, KC.F11, KC.F12, KC.PSCREEN, KC.SCROLLLOCK, KC.PAUSE,
        KC.GRAVE, KC.N1, KC.N2, KC.N3, KC.N4, KC.N5, KC.N6, KC.N7, KC.N8, KC.N9, KC.N0, KC.MINUS, KC.EQUAL, nokey, KC.BSPC, KC.INS, KC.HOME, KC.PGUP,
        KC.TAB, nokey, KC.Q, KC.W, KC.E, KC.R, KC.T, KC.Y, KC.U, KC.I, KC.O, KC.P, KC.LBRC, KC.RBRC, KC.BSLS, KC.DEL, KC.END, KC.PGDN,
        KC.CAPS, nokey, KC.A, KC.S, KC.D, KC.F, KC.G, KC.H, KC.J, KC.K, KC.L, KC.SCLN, KC.QUOT, KC.NUHS, KC.ENT, nokey, nokey, nokey,
        KC.LSFT, KC.NONUS_BSLASH, KC.Z, KC.X, KC.C, KC.V, KC.B, KC.N, KC.M, KC.COMM, KC.DOT, KC.SLSH, nokey, KC.RSHIFT, nokey, nokey, KC.UP, nokey,
        KC.LCTL, KC.LGUI, nokey, KC.LALT, nokey, nokey, KC.SPC, nokey,nokey, nokey, KC.RALT, KC.RGUI, nokey, KC.MO(1), KC.RCTRL, KC.LEFT, KC.DOWN, KC.RIGHT,
    ],
    [
    #Layer 1
        KC.TRNS, nokey, KC.F13, KC.F14, KC.F15, KC.F16, nokey, KC.F17, KC.F18, KC.F19, KC.F20, KC.F21, KC.F22, KC.F23, KC.F24, KC.MUTE, KC.VOLD, KC.VOLU,
        KC.TRNS, KC.TRNS, KC.TRNS, KC.TRNS, KC.TRNS, KC.TRNS, KC.TRNS, KC.TRNS, KC.TRNS, KC.TRNS, KC.TRNS, KC.TRNS, KC.TRNS, nokey, KC.TRNS, KC.TRNS, KC.TRNS, KC.TRNS,
        KC.TRNS, nokey, KC.TRNS, KC.TRNS, KC.TRNS, KC.TRNS, KC.TRNS, KC.TRNS, KC.TRNS, KC.TRNS, KC.TRNS, KC.TRNS, KC.TRNS, KC.TRNS, KC.TRNS, KC.TRNS, KC.TRNS, KC.TRNS,
        KC.TRNS, nokey, KC.TRNS, KC.TRNS, KC.TRNS, KC.TRNS, KC.TRNS, KC.TRNS, KC.TRNS, KC.TRNS, KC.TRNS, KC.TRNS, KC.TRNS, KC.TRNS, nokey, nokey, nokey, nokey,
        KC.TRNS, KC.TRNS, KC.TRNS, KC.TRNS, KC.TRNS, KC.TRNS, KC.TRNS, KC.TRNS, KC.TRNS, KC.TRNS, KC.TRNS, KC.TRNS, nokey, KC.TRNS, nokey, nokey, KC.TRNS, nokey,
        KC.TRNS, KC.TRNS, nokey, KC.TRNS, nokey, nokey, KC.TRNS, nokey, nokey, nokey, KC.TRNS, KC.TRNS, nokey, KC.TRNS, KC.TRNS, KC.TRNS, KC.TRNS, KC.TRNS,
    ],
]

def usbfunc():
    
    if __name__ == '__main__':
        led.duty_cycle=16384
        led.frequency=144
        print("Started")
        envkb.go()
        raise Exception('Something has caused an error.')
        
try:
    usbfunc()
except KeyboardInterrupt:
    led.duty_cycle=0
    print("Keyboard Interrupt")
except Exception as e:
    print(e)
    led.duty_cycle=0
    supervisor.reload()


supervisor.reload()

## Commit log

2021-02-16 Add KiCad Bits
    all the KiCad bits for this project.
    [keyboard.kicad_pcb, keyboard.sch]
2021-02-16 Renamed Files to correct names
    [ENV_KB.kicad_pcb, ENV_KB.sch]
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2021-02-18 Undid diode mess / Done rest of Switch Traces
    [ENV_KB.kicad_pcb]
2021-02-18 Replaced Diodes in horizontal stack
    [ENV_KB.kicad_pcb]
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2021-02-19 possible solution to MCU orientation and space usage dilemma
    [ENV_KB.kicad_pcb, ENV_KB.sch]
2021-02-19 Finished remaining traces, need to do TP# Vbus and GND for usb now.
    [ENV_KB.kicad_pcb, ENV_KB.sch]
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2021-02-21 some additional final updates before having a first batch made
    [ENV_KB.kicad_pcb]
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2021-02-21 replaced Micro B with Type C due to parts avaliability
    [ENV_KB.kicad_pcb, ENV_KB.sch]
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2021-02-27 more adjustments
    this version i have sent to JLCPCB
    [ENV_KB.kicad_pcb]
2021-03-04 Adjustments for Rev.B
    added a place for the I2C header and traces + a USB power LED and a few small tweaks
    [ENV_KB.kicad_pcb, ENV_KB.sch]
2021-03-05 Corrections, Part Numbers, Cleanups, etc
    I removed a couple of un-needed libraries finally and corrected a bunch of stuff.
    also added LSCS part numbers in the schematic
    probably some other stuff I forgot
    [ENV_KB.kicad_pcb, ENV_KB.sch]
2021-03-07 various things, silk screen bits, cleaning up, etc
    [ENV_KB.kicad_pcb]
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2021-03-23 Added Reset Button, Adjusted some trace routes, Updated Schematic
    [B3F-1000.step, ENV_KB.kicad_pcb, ENV_KB.sch]
2021-03-29 Initial Ansi Support
    adding support to fit ansi backslash and enter key
    probably needs some double checking +this would be incompatible with the current keymap unless you dont mind a non functional enter key and a ANSI backslash which does enter instead.
    [ENV_KB.kicad_pcb, ENV_KB.sch]
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2021-03-29 ANSI updates and cleaning up
    just neatened up some traces, added some markings.
    [ENV_KB.csv, ENV_KB.kicad_pcb, ENV_KB.sch]
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2021-04-03 Uploaded KMK files for keyboard
    This is a optimized version of KMK with the LED fix and the legacy keymap for this keyboard.
    if your pico runs circuitpython you can drag and drop the contents of this zip onto your pico.
2021-04-06 Designing a basic plate design that can be exported to SVG
    Attempting to use KICAD for mechanical CAD design, Im utilizing the user layers to work on a plate design
    [ENV_KB.kicad_pcb]
2021-04-06 more plate design work + screwholes
    I would like for this keyboard to feel like a solid unit like a individual object not an assembly of a few, something sturdy and light.
    [ENV_KB.kicad_pcb, ENV_KB.sch]
2021-04-06 Some additional changes to plate design
    depending on which height the plate is mounted at we could clear the diodes and just leave a cut out for where the MCU goes, maybe USB port too, would like to add more mounting holes in that case.
    [ENV_KB.kicad_pcb]
2021-04-07 Housekeeping
    this folder is getting very messy so I its high time for a bit of spring cleaning.
    [ENV_KB.csv]
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2021-04-09 Adding more mount holes and some alignment adjustments
    [ENV_KB.kicad_pcb, ENV_KB.sch]
2021-04-09 moved a bunch of traces and made the board slimmer
    [ENV_KB.kicad_pcb]
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2021-04-12 Reset MCU on Exception being raised
    This is a workaround for when the host computer resets and causes a error in Circuitpython or KMK (not sure which) but to stop the keyboard from becoming useless without reconnecting it this will now make it reset.
2021-04-15 Removed un-needed via and adjusted traces for ground plane fill.
    [ENV_KB.kicad_pcb]
2021-04-15 Corrected Trace issue and added Gerber files
    I added a Gerber zip, BOM and position files so you can send those off to JLCPCB if you want your own keyboard PCBs made.
    [BOM.csv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]
2021-04-16 Some small updates and corrections
    [ENV_KB.kicad_pcb, ENV_KB.sch]
2021-04-20 Updated Gerber Zip and Added Pictures of PCB
    [ENV_KB-B_Cu.gbl, ENV_KB-B_Mask.gbs, ENV_KB-B_Paste.gbp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]
2021-04-20 Corrected an error with the laser cut SVG
    [ENV_KB.kicad_pcb]
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2021-05-10 Redesigned Plate, resized board, adjusted mount holes
    [ENV_KB.kicad_pcb]
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2021-05-12 a few small adjustments to traces and pads
    [ENV_KB.kicad_pcb]
2021-05-13 Added a new mount hole and updated gerber files
    [ENV_KB-B_Cu.gbl, ENV_KB-B_Mask.gbs, ENV_KB-B_SilkS.gbo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]
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2021-05-14 Corrected Gerber and Laser Cut DXFs
    [ENV_KB-B_Cu.gbl, ENV_KB-B_Mask.gbs, ENV_KB-B_Paste.gbp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]
2021-05-20 Cleaned up Repo and made blank bottom PCB
    [B3F-1000.step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]
2021-05-20 Changed Button to B3U from EVQ + smaller LED resistor
    [ENV_KB-B_Cu.gbl, ENV_KB-B_Mask.gbs, ENV_KB-B_Paste.gbp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]
2021-05-22 Re aligned all diodes and re-did traces for all diodes
    [ENV_KB.kicad_pcb, ENV_KB.sch]
2021-05-22 Corrected bottom plate size and created switch plate.
    [ENV_KB-Back-B_Cu.gbl, ENV_KB-Back-B_Mask.gbs, ENV_KB-Back-B_Paste.gbp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]
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2021-05-23 adjusted traces, placements and clearances on main PCB and re-generated Gerber, Bom and Position file
    [ENV_KB-B_Cu.gbl, ENV_KB-B_Mask.gbs, ENV_KB-B_Paste.gbp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]
2021-05-24 some small alignment tweaks and corrections
    [ENV_KB.kicad_pcb, ENV_KB.sch]
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2021-05-27 Changed Logo and fixed missing silkscreen for I2C header
    [ENV_KB-Back.kicad_pcb, ENV_KB.kicad_pcb]
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2021-05-31 General checkover, Generated upto date Gerbers for JLCPCB
    [ENV_KB-B_Cu.gbl, ENV_KB-B_Mask.gbs, ENV_KB-B_Paste.gbp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]
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2021-06-11 increased Resistor value for led as it was too bright.
    [ENV_KB.sch]
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2021-06-14 Small Corrections to traces
2021-06-15 Updated Guide and documentation / Generated Gerbers for RGB keyboard
    [ENV_KB_RGB-B_Cu.gbl, ENV_KB_RGB-B_Mask.gbs, ENV_KB_RGB-B_Paste.gbp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]
2021-06-15 cleanup and some small fixes as per DRC
    [ENV_KB.kicad_pcb]
2021-06-17 Corrected some netlist issues on backplate and switch plate + cleanup of stuff.
    [ENV_KB-B_Cu.gbl, ENV_KB-B_Mask.gbs, ENV_KB-B_Paste.gbp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]
2021-06-17 Corrected a mistake in the silkscreen, overlapping a contributor initials and footprint
    [ENV_KB.kicad_pcb, ENV_KB.sch]
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2021-07-14 Changed all mount holes to M2 and added some pads around the holes to avoid scratches being visible on pcbs
    [Acrylic.kicad_pcb, Acrylic.sch, ENV_KB-Back.kicad_pcb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]
2021-07-16 Created a Acrylic cover plate incase you don't want to use a switch plate.
    [Acrylic.kicad_pcb, Acrylic.sch]
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2021-07-28 replaced buck boost with a LDO (AP2127K-3.3)
    [ENV_KB_RP2040.kicad_pcb, ENV_KB_RP2040.sch]
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2021-08-02 Swapped Reset button for cheaper Alps SKRK
    [ENV_KB.kicad_pcb, ENV_KB.sch]
2021-08-16 corrected all DRC Errors, all vias on pads as well as separated vbus and vsys in the schematic properly.
    [ENV_KB_RP2040.kicad_pcb, ENV_KB_RP2040.sch]
2021-08-31 updated switch plate(s) to include a slot for installing pcb mount stabs
    [Acrylic.kicad_pcb, ENV_KB-Top.kicad_pcb]
2021-08-31 started work on a test gasket/spacer type thing for front and back.
    [ENV_KB-Top-Eco2_User.dxf, ENV_KB-Top.kicad_pcb, ENV_KB.kicad_pcb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]
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2021-09-07 shrunk the PCBs width down to 347mm to comply with JLCPCBs max size for 4 layers.
    [ENV_KB_RGB.sch]
2021-09-07 Modified RGB/HS to be less wide so you can have it made via JLCPCB, Also made new logo and name for this version.
    [ENV_KB_RGB.sch]
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2021-09-14 committing this file to make sure I dont do a dumb
    its the switch plate for the Rev#1 PCB that has 3.2mm drill holes, I switched it to M2 later. aka the current files on this repo.
    [Acrylic-Eco2_User-Rev2.dxf]
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2021-10-01 corrected a couple of small issues
    [ENV_KB_RP2040.kicad_pcb]
2021-10-02 capitalized some refs to fix a issue with JLCPCB loading
    [ENV_KB_bom_jlc.csv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]
2021-10-05 generated laser cut files for current PCB version, changed footprint size of resistors to 1/4 instead of 1/8w
    [ENV_KB_RGB.sch, EnvKB-ALT-FrontPlate.dxf, EnvKB-ALT-RearPlate.dxf]
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2021-10-06 Fixed silkscreen and various other issues
    some traces were too close for comfort so Ive gone and spaced some stuff out and moved some other traces away from the edge of the pcb through a pair of vias
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2021-10-12 some tweaks and corrections, fixed some issues on rp2040 version
    [ENV_KB_RP2040.kicad_pcb]
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2021-10-20 General fixes, added missing credits, updated revision, fixed a couple of plane fill issues, updated logo and silkscreen pattern.
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2021-10-22 corrected some random duplicated traces and leftover tails.
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2021-10-25 fixed components that were no longer connected and added cutouts for directly soldering MCU onto PCB
    [ENV_KB_RGB.kicad_pcb]
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2021-10-26 Corrected resistor footprint and adjusted placement, added cutout for direct mount usb castellation.
    [ENV_KB_RGB.sch]
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2021-11-15 fixed a trace running too close to some switch holes
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2021-11-15 Corrected CPL
    [ENV_KB_RGB_cpl_jlc.csv]
2021-11-25 added cutout for USB TP pad soldering and a JST connector in the schematic
    [ENV_KB.kicad_pcb, ENV_KB.sch]
2021-11-26 swapped type-c port on hs version to allow for thicker switch plates (more than 2mm)
    [ENV_KB_RGB.sch, template.kicad_pcb, template.sch]
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2021-11-26 edited hotswap footprint to be stronger, swapped USB port, adjusted revision markers and credit markers
    [ENV_KB_RGB.sch, EnvKBTKL.kicad_pcb, EnvKBTKL.kicad_sch]
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2021-12-05 cleaned up libraries and stuff, need to fix some bits probably
    [B3F-1000.step, ENV_KB.kicad_pcb, ENV_KB.sch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]
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2021-12-10 Started Rework of RP2040 version (again)
    [ENV_KB_RP2040.kicad_pcb, ENV_KB_RP2040.sch]
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2022-02-04 fixed CPL to allow for SMD LED assembly
    [ENV_KB_RGB.csv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]
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2022-03-18 Created hotswap version with only 2 layer PCB based on RGB version.
    [EnvKB_HS.kicad_sch, EnvKB_HS.sch, EnvKB_HS_bom_jlc.csv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]
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2022-04-08 overall fixup and update of main Version
    [ENV_KB.kicad_sch]
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2022-04-21 fixed? ansi+iso+hotswap support I think but also file cleanup
    [ENV_KB_RGB.csv, ENV_KB_RGB.kicad_sch, ENV_KB_RGB_bom_jlc.csv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]
2022-05-03 various tweaks and adjustments, Generated Gerber however there is an issue with overlapping footprints in part selection
    [ENV_KB.kicad_pcb, ENV_KB_RGB.kicad_sch, ENV_KB_RGB_bom_jlc.csv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]
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2022-05-23 swapped footprint of various parts, updated the logo and tweaked some traces
    [ENV_KB.kicad_pcb, ENV_KB.kicad_sch]
2022-05-26 Overhauled original board deisgn and modified RGB board design, made sure native fillets were used, 45 or 90
    [ENV_KB_RGB.sch, ENV_KB_RGB_bom_jlc.csv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]
2022-05-27 moved power input for mcu to vsys and also tweaked a bunch of traces to look nicer
    [ENV_KB_RGB.kicad_sch]
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2022-06-02 roundified hotswap board and general corrections to other boards, RP2040 DRC fixes mainly
    [ENV_KB.kicad_pcb, EnvKB_HS.kicad_sch, EnvKB_HS.sch]
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2022-06-07 fixed some traces I didnt like
    [ENV_KB.kicad_pcb]
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2022-06-16 Unified board shape/size and mount holes + re-centered USB port to new size
    [ENV_KB.kicad_pcb]
2022-07-25 removed RP2040 version as it no longer fits with the direction of this project.
    [ENV_KB_RP2040.kicad_sch, ENV_KB_RP2040.sch]
2022-07-30 Swapped VBUS power to VSYS and fixed edge cut issues.
    [ENV_KB_RGB.kicad_sch]
2022-11-16 enlarged mount holes on HS version + increased clearance on some traces between diodes and plates holes, need to do this for whole board though
    [EnvKB_HS.kicad_sch]
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2023-02-13 added missing GND plane and added vias for more fill.
2023-04-15 fixed some issues with clearances, traces and zones.
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2024-04-16 fixed footprint causing error spam
    [EnvKB_HS.kicad_sch]
